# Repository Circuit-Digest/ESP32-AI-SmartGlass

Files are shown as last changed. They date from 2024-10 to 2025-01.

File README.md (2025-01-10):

# [ESP32-AI-SmartGlass](https://circuitdigest.com/videos/esp32-ai-smartglass)
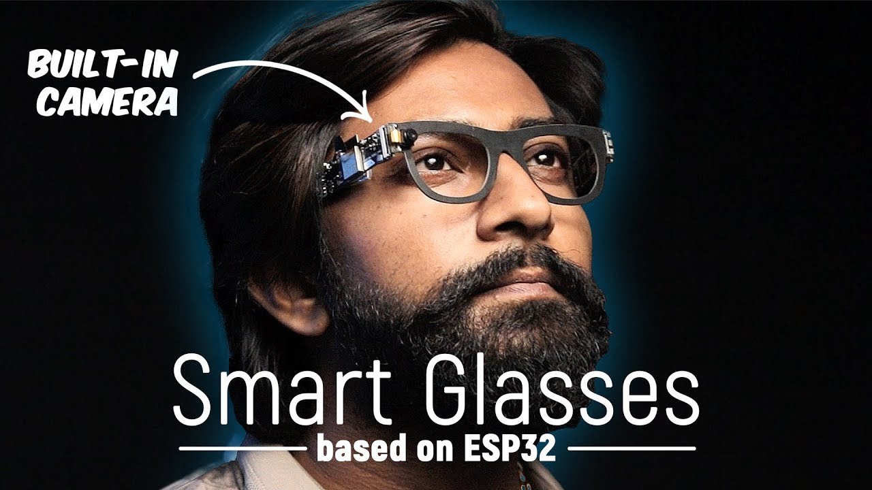
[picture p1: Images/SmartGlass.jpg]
Main Image


<br>
The ESP32 AI Smartglass is an innovative wearable device that blends the power of artificial intelligence with the convenience of home automation. Built around the ESP32-S3 mini microcontroller with 4MB of flash and 2MB of PSRAM, this smartglass is equipped to handle a variety of tasks efficiently. With built-in components like the INMP441 microphone, OV2640 camera, and MAX98357 I2S audio amplifier with a speaker, the smart glass is designed for seamless QR code-based control of household appliances. All the hardware is compactly integrated on a single PCB, which also forms the right leg of the smart glass, providing an elegant and functional solution. One of the standout features of the smart glass is its ease of use and versatility. By utilising the camera to scan QR codes, the user can control devices such as lights or fans connected to the same WiFi network. Once powered on, the RGB LEDs provide visual feedback during WiFi connection attempts, and the smart glass offers a welcome chime when the connection is successful. This smart glass removes the need for complex remote controls or hardwired switches, giving users a hands-free, efficient way to manage home automation with a simple glance at the desired QR code.

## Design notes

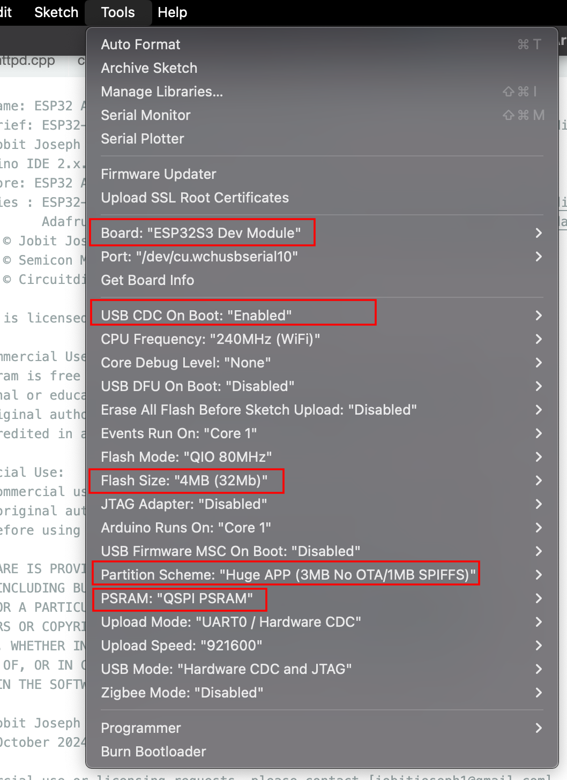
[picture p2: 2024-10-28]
Images/Arduino IDE Board Settings.png

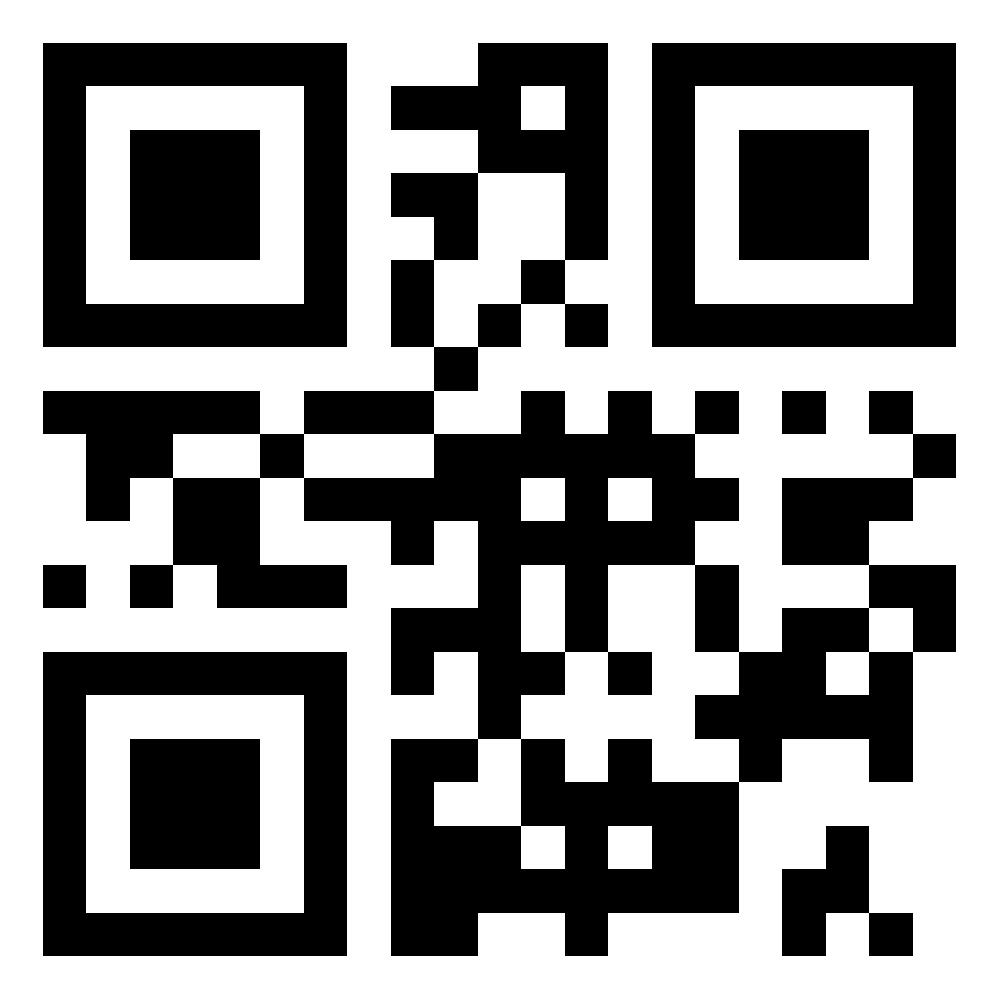
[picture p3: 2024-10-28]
Images/light.png

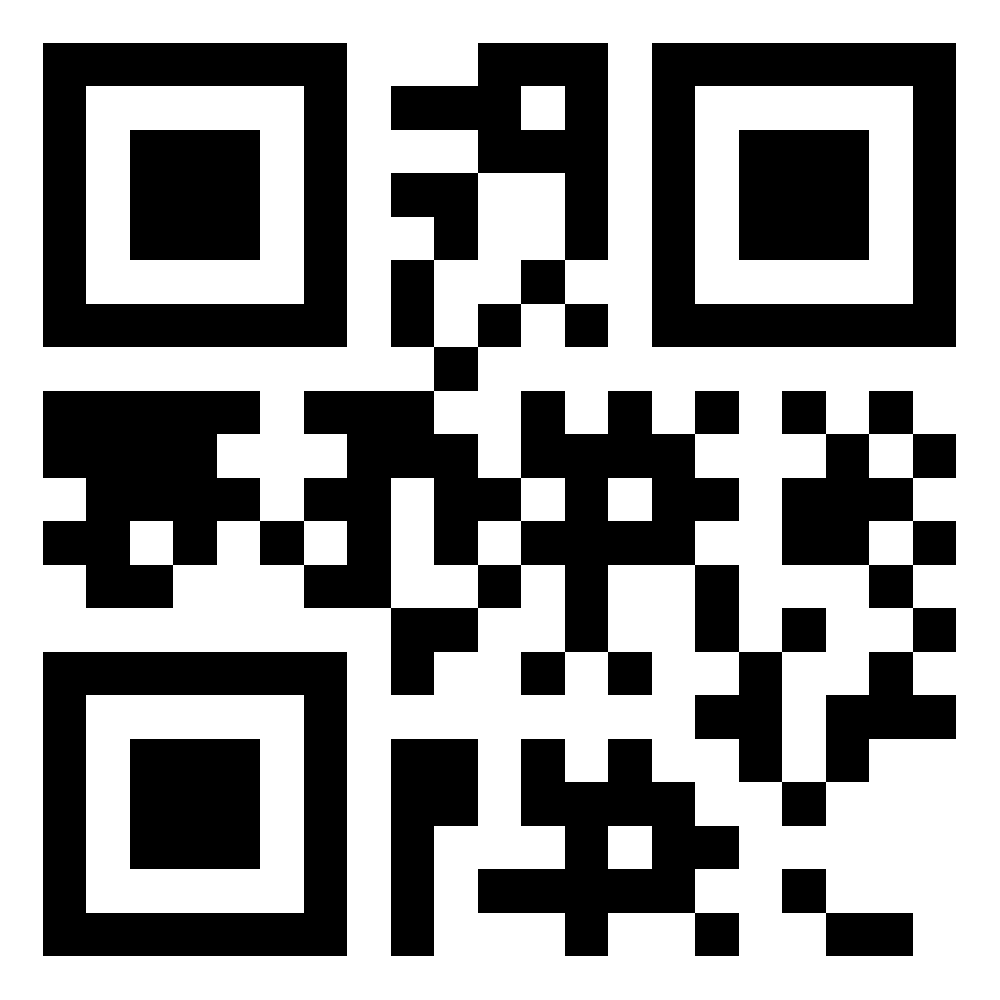
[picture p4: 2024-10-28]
Images/fan.png

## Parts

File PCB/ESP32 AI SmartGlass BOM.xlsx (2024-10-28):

Designator | Value | Footprint | Quantity | Manufacturer | Manufacturer Product Number | DigiKey Part Number | DigiKey Link
C1, C2, C4 | 4.7u | C603 | 3 | Samsung Electro-Mechanics | CL10A475KP8NNNC | 1276-1044-1-ND | https://www.digikey.in/en/products/detail/samsung-electro-mechanics/CL10A475KP8NNNC/3886702
C12 | 2.2uF | C603 | 1 | Samsung Electro-Mechanics | CL10B225KP8NNNC | 1276-1134-1-ND | https://www.digikey.in/en/products/detail/samsung-electro-mechanics/CL10B225KP8NNNC/3886792
C13 | 100nF | C603 | 1 | YAGEO | CC0603KRX7R7BB104 | 311-1088-1-ND | https://www.digikey.in/en/products/detail/yageo/CC0603KRX7R7BB104/302822
C20, C22, C24 | 100nF | C402 | 3 | Murata Electronics | GRM155R71C104KA88J | 490-6328-1-ND | https://www.digikey.in/en/products/detail/murata-electronics/GRM155R71C104KA88J/2610892
C21 | 4.7uF | C402 | 1 | Samsung Electro-Mechanics | CL05A475MP5NRNC | 1276-1482-1-ND | https://www.digikey.in/en/products/detail/samsung-electro-mechanics/CL05A475MP5NRNC/3887140
C23 | 2.2uF | C402 | 1 | Samsung Electro-Mechanics | CL05A225MP5NSNC | 1276-1467-1-ND | https://www.digikey.in/en/products/detail/samsung-electro-mechanics/CL05A225MP5NSNC/3887125
C25, C26, C27, C28 | 1uF | C603 | 4 | YAGEO | CC0603KRX7R7BB105 | 311-1446-1-ND | https://www.digikey.in/en/products/detail/yageo/CC0603KRX7R7BB105/2833611
C3 | 1nF | C603 | 1 | KEMET | C0603C102K5RAC7867 | 399-C0603C102K5RAC7867CT-ND | https://www.digikey.in/en/products/detail/kemet/C0603C102K5RAC7867/411081
D4 | 1N4148WT | D_SOD-523 | 1 | ANBON SEMICONDUCTOR (INT'L) LIMITED | 1N4148WT | 4530-1N4148WTCT-ND | https://www.digikey.in/en/products/detail/anbon-semiconductor-int-l-limited/1N4148WT/17284364
IC1 | LTC4065EDC | SON50P200X200X80-7N-D | 1 | Analog Devices Inc. | LTC4065EDC#TRMPBF | 505-LTC4065EDC#TRMPBFCT-ND | https://www.digikey.in/en/products/detail/analog-devices-inc/LTC4065EDC-TRMPBF/1115982
IC2 | ADM7171ACPZ-3.3-R7 | SON50P300X300X80-9N-D | 1 | Analog Devices Inc. | ADM7171ACPZ-3.3-R7 | 505-ADM7171ACPZ-3.3-R7CT-ND | https://www.digikey.in/en/products/detail/analog-devices-inc/ADM7171ACPZ-3-3-R7/5011539
IC5 | MAX98357AETE+T | QFN50P300X300X80-17N | 1 | Analog Devices Inc./Maxim Integrated | MAX98357AETE+T | MAX98357AETE+TCT-ND | https://www.digikey.in/en/products/detail/analog-devices-inc-maxim-integrated/MAX98357AETE-T/4936122
J2 | 10118194-0001LF | AMPHENOL_10118194-0001LF | 1 | Amphenol ICC (FCI) | 10118194-0001LF | 609-4618-1-ND | https://www.digikey.in/en/products/detail/amphenol-icc-(fci)/10118194-0001LF/2785382?productid=2785382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
J5 | Conn_01x24 | TE_2-1734839-4_1x24-1MP_P0.5mm_Horizontal | 1 | Amphenol ICC (FCI) | F33Z-1A7Q1-E8C24 | 609-F33Z-1A7Q1-E8C24CT-ND | https://www.digikey.in/en/products/detail/amphenol-cs-fci/F33Z-1A7Q1-E8C24/20415093
LED1 | Red | LED603 | 1 | Harvatek Corporation | B1911USD-20D000114U1930 | 3147-B1911USD-20D000114U1930CT-ND | https://www.digikey.in/en/products/detail/harvatek-corporation/B1911USD-20D000114U1930/15519991
R1 | 510R | R603 | 1 | YAGEO | RC0603FR-07510RL | 311-510HRCT-ND | https://www.digikey.in/en/products/detail/yageo/RC0603FR-07510RL/727285
R10, R9 | 10k | R402 | 2 | YAGEO | RC0402JR-0710KL | 311-10KJRCT-ND | https://www.digikey.in/en/products/detail/yageo/RC0402JR-0710KL/726418
R12 | 0R | R603 | 1 | Stackpole Electronics Inc | RMCF0603ZT0R00 | RMCF0603ZT0R00CT-ND | https://www.digikey.in/en/products/detail/stackpole-electronics-inc/RMCF0603ZT0R00/1756908
R2 | 2K | R603 | 1 | Panasonic Electronic Components | ERJ-3EKF2001V | P2.00KHCT-ND | https://www.digikey.in/en/products/detail/panasonic-electronic-components/ERJ-3EKF2001V/196183
R3 | 100K | R603 | 1 | Panasonic Electronic Components | ERJ-3EKF1003V | P100KHCT-ND | https://www.digikey.in/en/products/detail/panasonic-electronic-components/ERJ-3EKF1003V/196075
R4, R5 | 10k | R603 | 2 | Stackpole Electronics Inc | RMCF0603JT10K0 | RMCF0603JT10K0CT-ND | https://www.digikey.in/en/products/detail/stackpole-electronics-inc/RMCF0603JT10K0/1758104
SW1 | CUS-12TB | slide switch spdt | 1 | Nidec Components Corporation | CUS-12TB | 563-1102-1-ND | https://www.digikey.in/en/products/detail/nidec-components-corporation/CUS-12TB/1124222
SW2, SW3 | RST | Tactile 3x4x2mm TS-A010 | 2 | CIT Relay and Switch | CS1213AGF160 | 2449-CS1213AGF160CT-ND | https://www.digikey.in/en/products/detail/cit-relay-and-switch/CS1213AGF160/16607723
U2 | AP2127K-2.8 | SOT-23-5 | 1 | Diodes Incorporated | AP2127K-2.8TRG1 | AP2127K-2.8TRG1DICT-ND | https://www.digikey.in/en/products/detail/diodes-incorporated/AP2127K-2-8TRG1/4570641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
U3 | ESP32-S3-MINI-1U | ESP32-S2-MINI-1U | 1 | Espressif Systems | ESP32-S3-MINI-1-N4R2 | 1965-ESP32-S3-MINI-1-N4R2CT-ND | https://www.digikey.in/en/products/detail/espressif-systems/ESP32-S3-MINI-1-N4R2/22597234
U4 | AP2127K-1.5 | SOT-23-5 | 1 | Diodes Incorporated | AP2127K-1.8TRG1 | AP2127K-1.8TRG1DICT-ND | https://www.digikey.in/en/products/detail/diodes-incorporated/AP2127K-1-5TRG1/4470783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

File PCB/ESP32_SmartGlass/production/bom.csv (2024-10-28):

Designator | Footprint | Quantity | Value | LCSC Part #
BZ2 | JST_PH_B2B-PH-K_1x02_P2.00mm_Vertical | 1 | SMT-0540-S-R
C1, C2, C4 | 0603 | 3 | 4.7u
C12 | 0603 | 1 | 2.2uF
C13 | 0603 | 1 | 100nF
C20, C22 | 0402 | 2 | 100nf
C21 | 0402 | 1 | 4.7uf
C25, C26, C27, C28, C29, C30 | 0603 | 6 | 1u
C3 | 0603 | 1 | 1n
D1, D2 | LED_WS2812B-2020_PLCC4_2.0x2.0mm | 2 | WS2812B-2020
FB1, FB2 | 0805 | 2 | FerriteBead_Small
IC1 | SON50P200X200X80-7N-D | 1 | LTC4065EDC
IC2 | SON50P300X300X80-9N-D | 1 | ADM7171ACPZ-3.3-R7
IC5 | QFN50P300X300X80-17N | 1 | MAX98357AETE+T
J1 | PinHeader_1x02_P2.00mm_Vertical | 1 | Conn_01x02
J2 | AMPHENOL_10118194-0001LF | 1 | 10118194-0001LF
J3 | PinHeader_1x01_P2.54mm_Vertical | 1 | Conn_01x01
J5_2 | PinHeader_1x15_P1.00mm_Vertical | 1 | Conn_01x15
J5 | TE_2-1734839-4_1x24-1MP_P0.5mm_Horizontal | 1 | Conn_01x24
LED1 | 0603 | 1 | Red
MK1 | MIC_INMP441ACEZ-R7 | 1 | INMP441ACEZ-R7
R1 | 0603 | 1 | 510
R10, R9 | 0402 | 2 | 10k
R11, R6 | 0603 | 2 | NC
R12 | 0603 | 1 | 0R
R2 | 0603 | 1 | 2K
R3 | 0603 | 1 | 100K
R4, R5 | 0603 | 2 | 10k
SW1 | slide switch spdt | 1 | K3-1280S-F1
SW2 | Tactile 3x4x2mm TS-A010 | 1 | RST
SW3 | Tactile 3x4x2mm TS-A010 | 1 | BOOT
U2 | SOT-23-5 | 1 | AP2127K-2.8
U3 | ESP32-S2-MINI-1U | 1 | ESP32-S3-MINI-1U
U4 | SOT-23-5 | 1 | AP2127K-1.8

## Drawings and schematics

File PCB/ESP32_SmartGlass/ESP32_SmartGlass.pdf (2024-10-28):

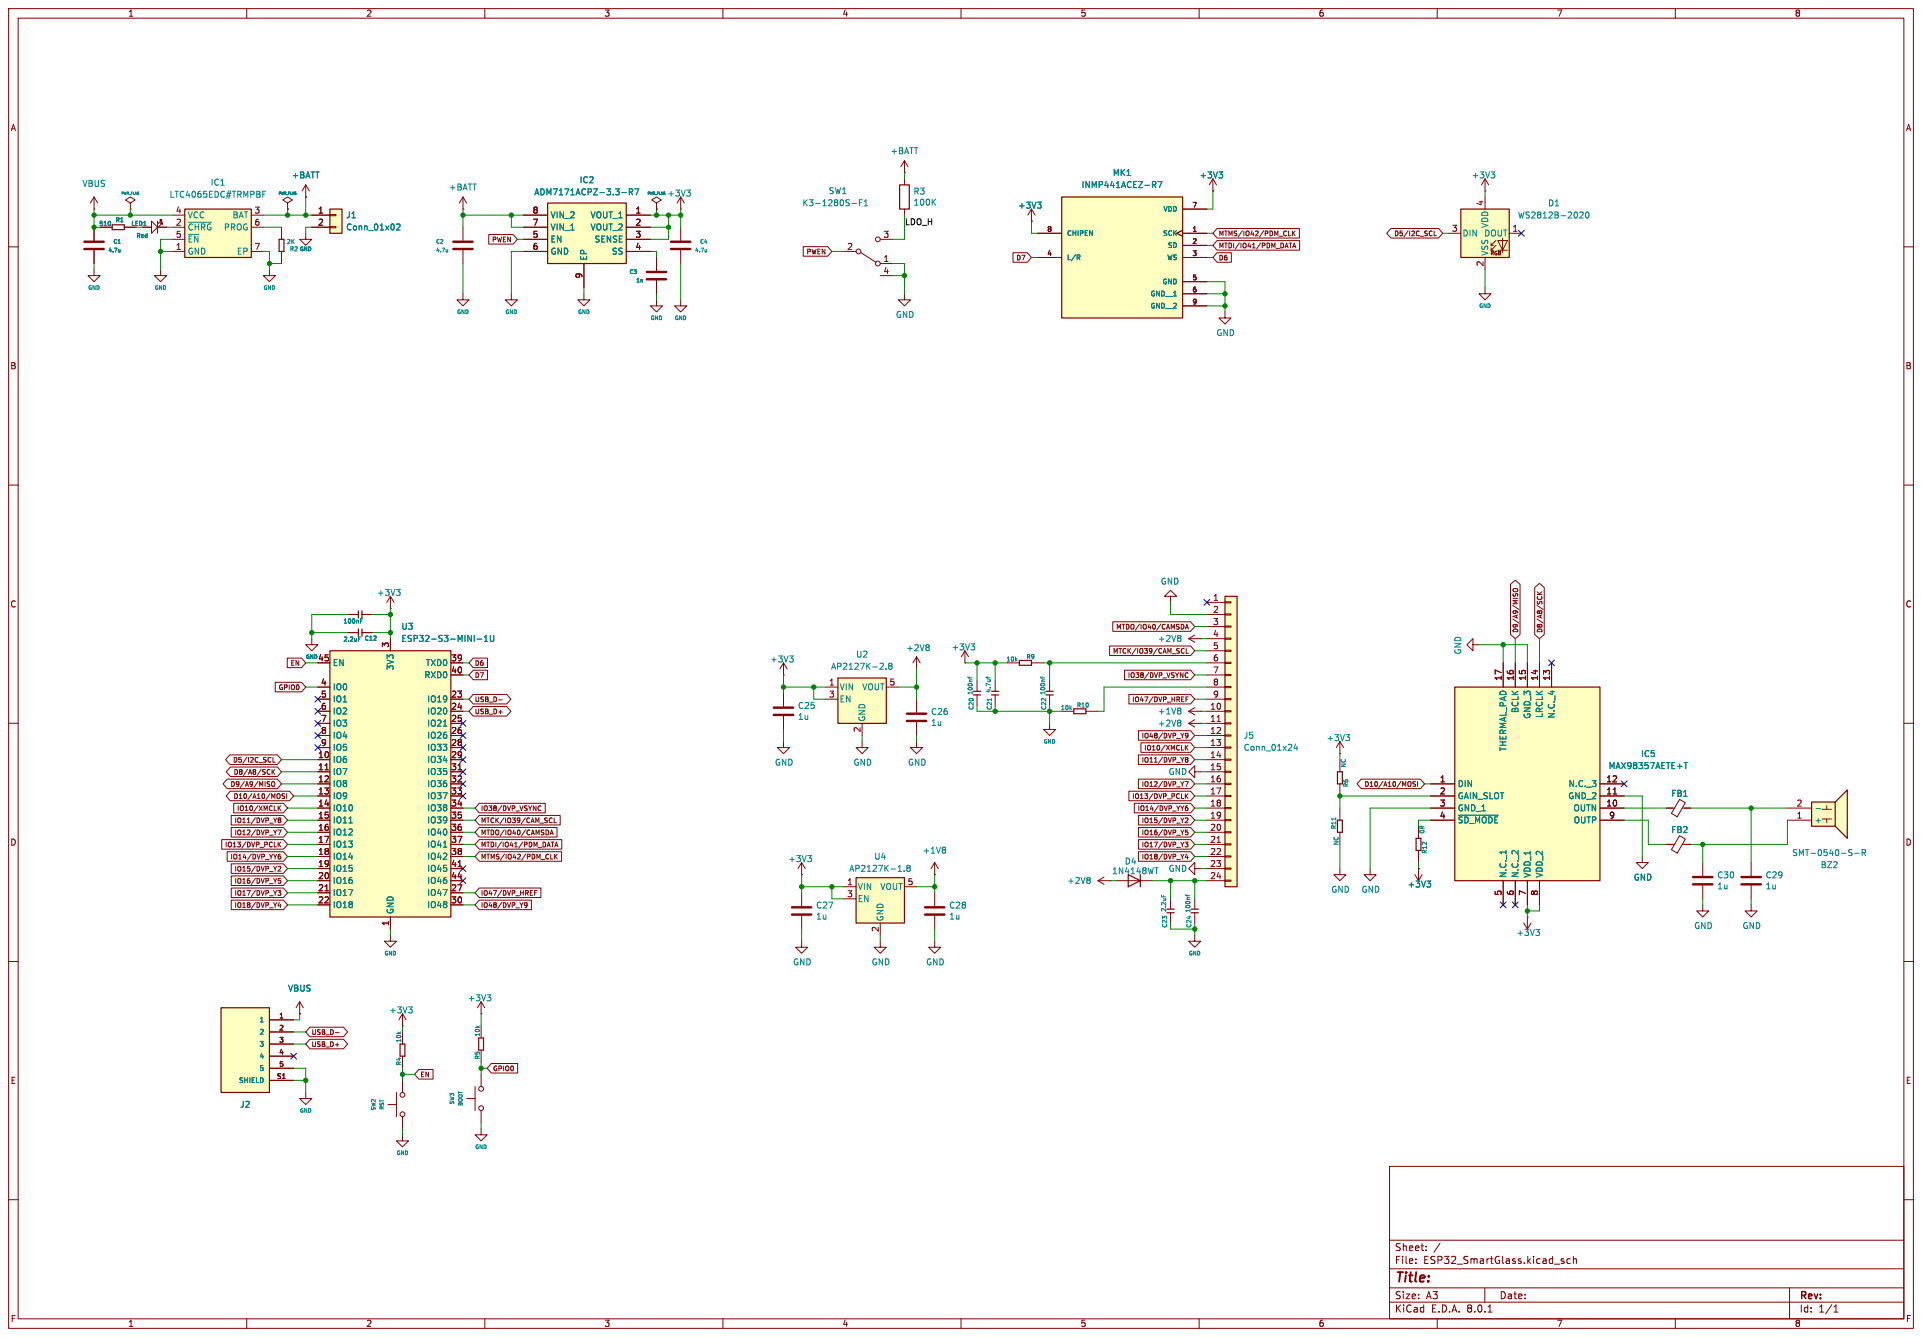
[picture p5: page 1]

D10/A10/MOSI MTCK/IO39/CAM_SCL MTDO/IO40/CAMSDA

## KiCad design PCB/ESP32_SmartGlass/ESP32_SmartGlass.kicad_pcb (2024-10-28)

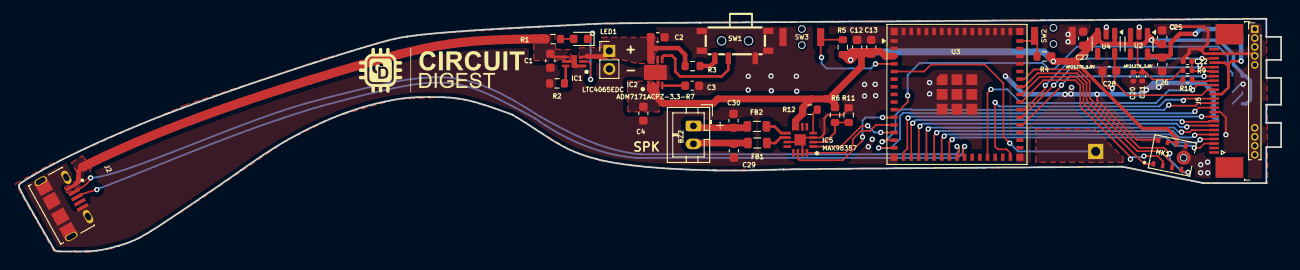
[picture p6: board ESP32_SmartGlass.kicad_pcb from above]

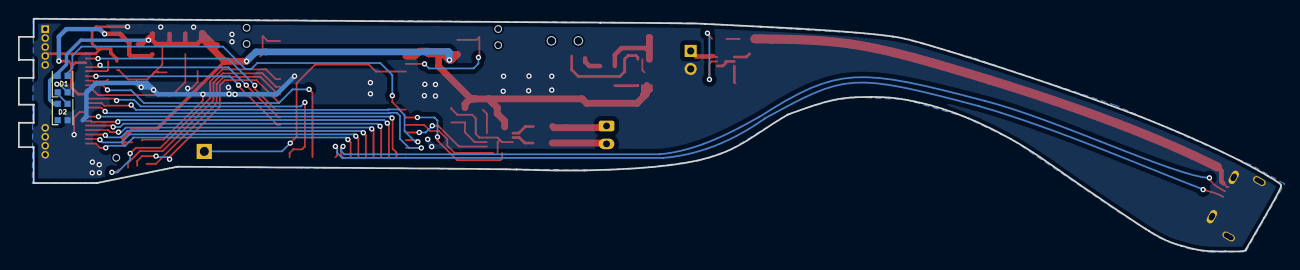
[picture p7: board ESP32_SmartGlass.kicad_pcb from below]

Board: 2 copper layers, 140.6 x 25.9 mm, 46 parts (2 on the bottom side), 48 nets.

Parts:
BZ2: SMT-0540-S-R; JST_PH_B2B-PH-K_1x02_P2.00mm_Vertical
C1, C2, C4: 4.7u; C_0603_1608Metric
C3: 1n; C_0603_1608Metric
C12: 2.2uF; C_0603_1608Metric
C13: 100nF; C_0603_1608Metric
C20, C22: 100nf; C_0402_1005Metric
C21: 4.7uf; C_0402_1005Metric
C25, C26, C27, C28, C29, C30: 1u; C_0603_1608Metric
D1, D2: WS2812B-2020; LED_WS2812B-2020_PLCC4_2.0x2.0mm
FB1, FB2: FerriteBead_Small; L_0805_2012Metric
IC1: LTC4065EDC; SON50P200X200X80-7N-D
IC2: ADM7171ACPZ-3.3-R7; SON50P300X300X80-9N-D
IC5: MAX98357AETE+T; QFN50P300X300X80-17N
J1: Conn_01x02; PinHeader_1x02_P2.00mm_Vertical
J2: 10118194-0001LF; AMPHENOL_10118194-0001LF
J3: Conn_01x01; PinHeader_1x01_P2.54mm_Vertical
J5: Conn_01x15; PinHeader_1x15_P1.00mm_Vertical
J5#2: Conn_01x24; TE_2-1734839-4_1x24-1MP_P0.5mm_Horizontal
LED1: Red; LED_0603_1608Metric
MK1: INMP441ACEZ-R7; MIC_INMP441ACEZ-R7
R1: 510; R_0603_1608Metric
R2: 2K; R_0603_1608Metric
R3: 100K; R_0603_1608Metric
R4, R5: 10k; R_0603_1608Metric
R6, R11: NC; R_0603_1608Metric
R9, R10: 10k; R_0402_1005Metric
R12: 0R; R_0603_1608Metric
SW1: K3-1280S-F1; slide switch spdt
SW2: RST; Tactile 3x4x2mm TS-A010
SW3: BOOT; Tactile 3x4x2mm TS-A010
U2: AP2127K-2.8; SOT-23-5
U3: ESP32-S3-MINI-1U; ESP32-S2-MINI-1U
U4: AP2127K-1.8; SOT-23-5

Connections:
+1V8: C28.1, J5#2.10, U4.5 (VOUT)
+2V8: C26.1, J5#2.4, J5#2.11, U2.5 (VOUT)
+3V3: C4.1, C12.2, C13.2, C20.1, C21.1, C25.1, C27.1, D1.4 (VDD), D2.4 (VDD), IC2.1 (VOUT_1), IC2.2 (VOUT_2), IC2.3 (SENSE), IC5.7 (VDD_1), IC5.8 (VDD_2), MK1.7 (VDD), MK1.8 (CHIPEN), R4.1, R5.1, R6.1, R9.1, R12.2, U2.1 (VIN), U2.3 (EN), U3.3 (3V3), U4.1 (VIN), U4.3 (EN)
+BATT: C2.1, IC1.3 (BAT), IC2.7 (VIN_1), IC2.8 (VIN_2), J1.1, R3.1
/LDO_H: R3.2, SW1.3 (C)
D5/I2C_SCL: D1.3 (DIN), U3.10 (IO6)
D6: MK1.3 (WS), U3.39 (TXD0)
D7: MK1.4 (L/R), U3.40 (RXD0)
D8/A8/SCK: IC5.14 (LRCLK), U3.11 (IO7)
D9/A9/MISO: IC5.16 (BCLK), U3.12 (IO8)
D10/A10/MOSI: IC5.1 (DIN), U3.13 (IO9)
EN: R4.2, SW2.2, U3.45 (EN)
GND: C1.2, C2.2, C3.2, C4.2, C12.1, C13.1, C20.2, C21.2, C22.2, C25.2, C26.2, C27.2, C28.2, C29.2, C30.2, D1.2 (VSS), D2.2 (VSS), IC1.1 (GND), IC1.5 (~EN), IC1.7 (EP), IC2.6 (GND), IC2.9 (EP), IC5.3 (GND_1), IC5.11 (GND_2), IC5.15 (GND_3), IC5.17 (THERMAL_PAD), J1.2, J2.5, J2.S1 (SHIELD), J2.S2 (SHIELD__1), J5.1, J5.2, J5.3, J5.4, J5.5, J5.12, J5.13, J5.14, J5.15, J5#2.2, J5#2.15, MK1.5 (GND), MK1.6 (GND__1), MK1.9 (GND__2), R2.2, R10.1, R11.1, SW1.1 (A), SW1.4, SW2.1, SW3.1, U2.2 (GND), U3.1 (GND), U3.2 (GND), U3.42 (GND), U3.43 (GND), U3.46 (GND), U3.47 (GND), U3.48 (GND), U3.49 (GND), U3.50 (GND), U3.51 (GND), U3.52 (GND), U3.53 (GND), U3.54 (GND), U3.55 (GND), U3.56 (GND), U3.57 (GND), U3.58 (GND), U3.59 (GND), U3.60 (GND), U3.61 (GND), U3.62 (GND), U3.63 (GND), U3.64 (GND), U3.65 (GND), U4.2 (GND)
GPIO0: R5.2, SW3.2, U3.4 (IO0)
IO10/XMCLK: J5#2.13, U3.14 (IO10)
IO11/DVP_Y8: J5#2.14, U3.15 (IO11)
IO12/DVP_Y7: J5#2.16, U3.16 (IO12)
IO13/DVP_PCLK: J5#2.17, U3.17 (IO13)
IO14/DVP_YY6: J5#2.18, U3.18 (IO14)
IO15/DVP_Y2: J5#2.19, U3.19 (IO15)
IO16/DVP_Y5: J5#2.20, U3.20 (IO16)
IO17/DVP_Y3: J5#2.21, U3.21 (IO17)
IO18/DVP_Y4: J5#2.22, U3.22 (IO18)
IO38/DVP_VSYNC: J5#2.7, U3.34 (IO38)
IO47/DVP_HREF: J5#2.9, U3.27 (IO47)
IO48/DVP_Y9: J5#2.12, U3.30 (IO48)
MTCK/IO39/CAM_SCL: J5#2.5, U3.35 (IO39)
MTDI/IO41/PDM_DATA: MK1.2 (SD), U3.37 (IO41)
MTDO/IO40/CAMSDA: J5#2.3, U3.36 (IO40)
MTMS/IO42/PDM_CLK: MK1.1 (SCK), U3.38 (IO42)
unnamed: BZ2.1 (+), C30.1, FB2.2
unnamed: BZ2.2 (-), C29.1, FB1.2
unnamed: D1.1 (DOUT), D2.3 (DIN)
unnamed: IC1.6 (PROG), R2.1
unnamed: IC1.2 (~CHRG), LED1.1 (K)
unnamed: C3.1, IC2.4 (SS)
unnamed: IC5.2 (GAIN_SLOT), R6.2, R11.2
unnamed: FB1.1, IC5.10 (OUTN)
unnamed: FB2.1, IC5.9 (OUTP)
unnamed: IC5.4 (~SD_MODE), R12.1
unnamed: J3.1, U3.5 (IO1)
unnamed: C22.1, J5#2.6, R9.2
unnamed: J5#2.8, R10.2
unnamed: LED1.2 (A), R1.2
PWEN: IC2.5 (EN), SW1.2 (B)
USB_D+: J2.3, U3.24 (IO20)
USB_D-: J2.2, U3.23 (IO19)
VBUS: C1.1, IC1.4 (VCC), J2.1, R1.1

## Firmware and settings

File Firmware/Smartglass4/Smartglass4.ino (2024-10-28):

/*
 * Project Name: ESP32 AI Smart Glass
 * Project Brief: ESP32-S3 based smart glass equiped with camera, I2S amp and Memes Microphone. Capable of home automation with QRCode.
 * Author: Jobit Joseph @ https://github.com/jobitjoseph
 * IDE: Arduino IDE 2.x.x
 * Arduino Core: ESP32 Arduino Core V 3.0.5
 * Dependencies : ESP32-audioI2S Library V 3.0.12 @ https://github.com/schreibfaul1/ESP32-audioI2S
 *                Adafruit Neopixel Library V 1.12.3 @ https://github.com/adafruit/Adafruit_NeoPixel
 * Copyright © Jobit Joseph
 * Copyright © Semicon Media Pvt Ltd
 * Copyright © Circuitdigest.com
 * 
 * This code is licensed under the following conditions:
 *
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
 * 2. Commercial Use:
 * For any commercial use of this software, you must obtain a separate license
 * from the original author. Contact the author for permissions or licensing
 * options before using this software for commercial purposes.
 *
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
 * Author: Jobit Joseph
 * Date: 18 October 2024
 *
 * For commercial use or licensing requests, please contact [jobitjoseph1@gmail.com].
 */

#include "esp_camera.h"
#include <WiFi.h>
#include <Adafruit_NeoPixel.h>
#include "Audio.h"
#include "FS.h"
#include <LittleFS.h>
#include <HTTPClient.h>
#define I2S_DOUT 9
#define I2S_BCLK 8
#define I2S_LRC 7
#define RGBPIN 6
#define NUMPIXELS 2
#define FORMAT_LITTLEFS_IF_FAILED true
Adafruit_NeoPixel pixels(NUMPIXELS, RGBPIN, NEO_GRB + NEO_KHZ800);
Audio audio;
WiFiClientSecure client;           // Secure client for HTTPS communication
String receivedText = "";          // Buffer to hold the received serial text
#define CAMERA_MODEL_XIAO_ESP32S3  // Has PSRAM
#include "camera_pins.h"

// ===========================
// Enter your WiFi credentials
// ===========================

const char* ssid = "circuitdigest";
const char* password = "circuitdigest123";

String serverName = "www.circuitdigest.cloud";  // Server domain
String serverPath = "/readqrcode";              // API endpoint path
const int serverPort = 443;                     // HTTPS port
String apiKey = "0Sv8M7UgxMtB";                 // Replace "xxx" with your API key

bool shouldReconnect = false;  // Flag to indicate Wi-Fi disconnection
unsigned long LastConFailedTime = 0;
int threshold = 1000;
bool touchdetected = false;
bool touchreleased = false;
bool EQ1 = false;
bool EQ2 = false;
void startCameraServer();
void setupLedFlash(int pin);
void TouchITR() {
  touchdetected = (touchdetected == false) ? true : false;
  touchreleased = (touchdetected == true) ? touchreleased : true;
}
void initWiFi() {
  Serial.print("Connecting to ");
  Serial.println(ssid);
  //audio.connecttoFS(LittleFS, "/Connecting.mp3");
  WiFi.disconnect();
  WiFi.mode(WIFI_STA);
  WiFi.begin(ssid, password);
  WiFi.setSleep(false);
  unsigned long startAttemptTime = millis();
  while (WiFi.status() != WL_CONNECTED) {
    if (millis() - startAttemptTime > 15000) {  // Timeout after 10 seconds
      Serial.println("Failed to connect to WiFi");
      //audio.connecttoFS(LittleFS, "/ConnectionFailed.mp3");
      LastConFailedTime = millis();
      return;  // Exit if unable to connect
    }
    delay(250);
    Serial.print(".");
    pixels.setPixelColor(0, pixels.Color(0, 0, 255));
    pixels.show();
    delay(250);
    pixels.clear();
    pixels.show();
    touchreleased = false;
  }
}
void onWifiEvent(WiFiEvent_t event) {
  switch (event) {
    case ARDUINO_EVENT_WIFI_STA_GOT_IP:
      Serial.println("");
      Serial.println("Connected to Wi-Fi successfully.");
      Serial.print("IP address: ");
      Serial.println(WiFi.localIP());
      //audio.connecttoFS(LittleFS, "/WiFiActive.mp3");
      shouldReconnect = false;  // Reset flag on successful connection
      break;

    case WIFI_EVENT_STA_DISCONNECTED:
      Serial.println("Disconnected from Wi-Fi, will try to reconnect...");
      shouldReconnect = true;  // Set flag to reconnect in the loop
      break;

    default:
      break;
  }
}
void initFS() {
  if (!LittleFS.begin(FORMAT_LITTLEFS_IF_FAILED)) {
    Serial.println("LittleFS Mount Failed");
    return;
  }
}

void togglePinOnESP8266(const char* esp8266_hostname) {
  if (WiFi.status() == WL_CONNECTED) {
    HTTPClient http;
    String url = String("http://") + esp8266_hostname + ".local/toggle";
    http.begin(url);
    int httpCode = http.GET();
    http.end();
  }
}

int getPinStateFromESP8266(const char* esp8266_hostname) {
  if (WiFi.status() == WL_CONNECTED) {
    HTTPClient http;
    String url = String("http://") + esp8266_hostname + ".local/state";
    http.begin(url);
    int httpCode = http.GET();
    String payload = http.getString();  // Get the response

    http.end();

    // Convert response to 0 or 1 based on the state
    if (payload == "HIGH") {
      return 1;
    } else if (payload == "LOW") {
      return 0;
    }
  }
  return -1;  // Return -1 if there is an error
}
/*
// Function to extract a JSON array value by key
String extractJsonArrayValue(const String& jsonString, const String& key) {
  int keyIndex = jsonString.indexOf(key);
  if (keyIndex == -1) {
    return "";
  }

  int startIndex = jsonString.indexOf('[', keyIndex);
  int endIndex = jsonString.indexOf(']', startIndex);

  if (startIndex == -1 || endIndex == -1) {
    return "";
  }

  return jsonString.substring(startIndex, endIndex + 1);
}


// Function to extract a JSON array value by key
String extractJsonArrayValue(const String& jsonString, const String& key) {
  int keyIndex = jsonString.indexOf(key);
  if (keyIndex == -1) {
    return "";
  }

  int startIndex = jsonString.indexOf('[', keyIndex);
  int endIndex = jsonString.indexOf(']', startIndex);

  if (startIndex == -1 || endIndex == -1) {
    return "";
  }

  // Extract the string inside the array, remove the square brackets and quotes
  String extractedArray = jsonString.substring(startIndex + 1, endIndex);
  extractedArray.replace("\"", ""); // Remove the double quotes

  return extractedArray;
}
*/
String extractJsonArrayValue(const String& jsonString, const String& key) {
    int keyIndex = jsonString.indexOf(key);
    if (keyIndex == -1) {
        return "";
    }

    int startIndex = jsonString.indexOf('[', keyIndex);
    int endIndex = jsonString.indexOf(']', startIndex);

    if (startIndex == -1 || endIndex == -1) {
        return "";
    }

    // Extract the string inside the array, remove the square brackets and quotes
    String extractedArray = jsonString.substring(startIndex + 1, endIndex);
    extractedArray.replace("\"", ""); // Remove the double quotes

    // Split the extractedArray by commas and return the first element
    int commaIndex = extractedArray.indexOf(',');
    if (commaIndex != -1) {
        return extractedArray.substring(0, commaIndex); // Return the first value before the comma
    }

    // If there is no comma, return the extractedArray (it contains only one element)
    return extractedArray;
}

// Function to extract a JSON string value by key
String extractJsonStringValue(const String& jsonString, const String& key) {
  int keyIndex = jsonString.indexOf(key);
  if (keyIndex == -1) {
    return "";
  }

  int startIndex = jsonString.indexOf(':', keyIndex) + 2;
  int endIndex = jsonString.indexOf('"', startIndex);

  if (startIndex == -1 || endIndex == -1) {
    return "";
  }

  return jsonString.substring(startIndex, endIndex);
}

// Function to capture and send photo to the server
int sendPhoto() {
  camera_fb_t* fb = NULL;
  fb = esp_camera_fb_get();
  if (!fb) {
    Serial.println("Camera capture failed");
    touchreleased = false;
    pixels.setPixelColor(0, pixels.Color(255, 0, 0));
    pixels.show();
    delay(250);
    pixels.clear();
    pixels.show();
    return -1;
  }

  // Display success message
  Serial.println("Image Capture Success");
  // Connect to server
  Serial.println("Connecting to server:" + serverName);
  client.setInsecure();  // Skip certificate validation for simplicity

  pixels.setPixelColor(0, pixels.Color(0, 255, 0));
  pixels.show();

  if (client.connect(serverName.c_str(), serverPort)) {
    Serial.println("Connection successful!");
    String filename = apiKey + ".jpeg";

    // Prepare HTTP POST request
    String head = "--CircuitDigest\r\nContent-Disposition: form-data; name=\"imageFile\"; filename=\"" + filename + "\"\r\nContent-Type: image/jpeg\r\n\r\n";
    String tail = "\r\n--CircuitDigest--\r\n";
    uint32_t imageLen = fb->len;
    uint32_t extraLen = head.length() + tail.length();
    uint32_t totalLen = imageLen + extraLen;

    client.println("POST " + serverPath + " HTTP/1.1");
    client.println("Host: " + serverName);
    client.println("Content-Length: " + String(totalLen));
    client.println("Content-Type: multipart/form-data; boundary=CircuitDigest");
    client.println("Authorization:" + apiKey);
    client.println();
    client.print(head);

    // Send image data in chunks
    uint8_t* fbBuf = fb->buf;
    size_t fbLen = fb->len;
    for (size_t n = 0; n < fbLen; n += 1024) {
      if (n + 1024 < fbLen) {
        client.write(fbBuf, 1024);
        fbBuf += 1024;
      } else {
        size_t remainder = fbLen % 1024;
        client.write(fbBuf, remainder);
      }
    }

    client.print(tail);

    // Clean up
    esp_camera_fb_return(fb);

    // Wait for server response
    String response;
    long startTime = millis();
    while (client.connected() && millis() - startTime < 10000) {
      if (client.available()) {
        char c = client.read();
        response += c;
      }
    }
    Serial.println("Raw JSON Data: " + response);
    // Extract and display QR code data from response
    String qrCodeData = extractJsonArrayValue(response, "\"QR_code\"");
    String imageLink = extractJsonStringValue(response, "\"view_image\"");

    Serial.print("QR Data: ");
    Serial.println(qrCodeData);
    if (qrCodeData == "light") {
      EQ1 = true;
    } else if (qrCodeData == "fan") {
      EQ2 = true;
    } else {
      audio.connecttoFS(LittleFS, "/InvalidQR.mp3");
    }

    Serial.print("ImageLink: ");
    Serial.println(imageLink);

    // Serial.print("Response Json String: ");
    // Serial.println(response);


    //displayText("QR Code Data:\n\n" + qrCodeData);

    client.stop();
    touchreleased = false;
    pixels.clear();
    pixels.show();
    return 0;
  } else {
    Serial.println("Connection to server failed");
    touchreleased = false;
    pixels.setPixelColor(0, pixels.Color(255, 0, 0));
    pixels.show();
    delay(200);
    pixels.clear();
    pixels.show();
    pixels.setPixelColor(0, pixels.Color(255, 0, 0));
    pixels.show();
    delay(200);
    pixels.clear();
    pixels.show();
    return -2;
  }
}
void EQControl() {
  int pinstate;
  if (EQ1) {
    EQ1 = false;
    togglePinOnESP8266("esp8266-1");
    pinstate = getPinStateFromESP8266("esp8266-1");
    if (pinstate == 0) {
      audio.connecttoFS(LittleFS, "/LightOff.mp3");
    } else if (pinstate == 1) {
      audio.connecttoFS(LittleFS, "/LightOn.mp3");
    }
  } else if (EQ2) {
    EQ2 = false;
    togglePinOnESP8266("esp8266-2");
    pinstate = getPinStateFromESP8266("esp8266-2");
    if (pinstate == 0) {
      audio.connecttoFS(LittleFS, "/FanOff.mp3");
    } else if (pinstate == 1) {
      audio.connecttoFS(LittleFS, "/FanOn.mp3");
    }
  }
  touchreleased = false;
}

void setup() {
  Serial.begin(115200);
  Serial.setDebugOutput(true);
  Serial.println();

  camera_config_t config;
  config.ledc_channel = LEDC_CHANNEL_0;
  config.ledc_timer = LEDC_TIMER_0;
  config.pin_d0 = Y2_GPIO_NUM;
  config.pin_d1 = Y3_GPIO_NUM;
  config.pin_d2 = Y4_GPIO_NUM;
  config.pin_d3 = Y5_GPIO_NUM;
  config.pin_d4 = Y6_GPIO_NUM;
  config.pin_d5 = Y7_GPIO_NUM;
  config.pin_d6 = Y8_GPIO_NUM;
  config.pin_d7 = Y9_GPIO_NUM;
  config.pin_xclk = XCLK_GPIO_NUM;
  config.pin_pclk = PCLK_GPIO_NUM;
  config.pin_vsync = VSYNC_GPIO_NUM;
  config.pin_href = HREF_GPIO_NUM;
  config.pin_sccb_sda = SIOD_GPIO_NUM;
  config.pin_sccb_scl = SIOC_GPIO_NUM;
  config.pin_pwdn = PWDN_GPIO_NUM;
  config.pin_reset = RESET_GPIO_NUM;
  config.xclk_freq_hz = 20000000;
  config.frame_size = FRAMESIZE_UXGA;
  config.pixel_format = PIXFORMAT_JPEG;  // for streaming
  //config.pixel_format = PIXFORMAT_RGB565; // for face detection/recognition
  config.grab_mode = CAMERA_GRAB_WHEN_EMPTY;
  config.fb_location = CAMERA_FB_IN_PSRAM;
  //config.fb_location = CAMERA_FB_IN_DRAM;
  config.jpeg_quality = 12;
  config.fb_count = 1;

  // if PSRAM IC present, init with UXGA resolution and higher JPEG quality
  //                      for larger pre-allocated frame buffer.
  if (config.pixel_format == PIXFORMAT_JPEG) {
    if (psramFound()) {
      config.jpeg_quality = 10;
      config.fb_count = 2;
      config.grab_mode = CAMERA_GRAB_LATEST;
    } else {
      // Limit the frame size when PSRAM is not available
      config.frame_size = FRAMESIZE_SVGA;
      config.fb_location = CAMERA_FB_IN_DRAM;
    }
  } else {
    // Best option for face detection/recognition
    config.frame_size = FRAMESIZE_240X240;
#if CONFIG_IDF_TARGET_ESP32S3
    config.fb_count = 1;
#endif
  }



  // camera init
  esp_err_t err = esp_camera_init(&config);
  if (err != ESP_OK) {
    Serial.printf("Camera init failed with error 0x%x", err);
    return;
  }

  sensor_t* s = esp_camera_sensor_get();
  // initial sensors are flipped vertically and colors are a bit saturated
  if (s->id.PID == OV3660_PID) {
    s->set_vflip(s, 1);        // flip it back
    s->set_brightness(s, 1);   // up the brightness just a bit
    s->set_saturation(s, -2);  // lower the saturation
  }
  // drop down frame size for higher initial frame rate
  if (config.pixel_format == PIXFORMAT_JPEG) {
    s->set_framesize(s, FRAMESIZE_QVGA);
  }
/*
#if defined(CAMERA_MODEL_M5STACK_WIDE) || defined(CAMERA_MODEL_M5STACK_ESP32CAM)
  s->set_vflip(s, 1);
  s->set_hmirror(s, 1);
#endif
*/

// Setup LED FLash if LED pin is defined in camera_pins.h
#if defined(LED_GPIO_NUM)
  setupLedFlash(LED_GPIO_NUM);
#endif

  initFS();
  pixels.begin();
  pixels.show();
  pixels.setBrightness(64);
  audio.setPinout(I2S_BCLK, I2S_LRC, I2S_DOUT);
  audio.setVolume(21);
  audio.connecttoFS(LittleFS, "/WelcomeTone.mp3");
  // Register Wi-Fi event handler
  WiFi.onEvent(onWifiEvent);
  //audio.connecttoFS(LittleFS, "/Connecting.mp3");
  initWiFi();
  startCameraServer();

  Serial.print("Camera Ready! Use 'http://");
  Serial.print(WiFi.localIP());
  Serial.println("' to connect");

  touchAttachInterrupt(T1, TouchITR, threshold);
}

void loop() {
  audio.loop();  // Required to keep audio running
  if (WiFi.status() != WL_CONNECTED) {
    if (shouldReconnect || (millis() - LastConFailedTime > 10000)) {
      Serial.println("Reconnecting to Wi-Fi...");
      //audio.connecttoFS(LittleFS, "/Reconnecting.mp3");
      initWiFi();  // Reattempt connection
    }
    if (touchreleased) {
      touchreleased = false;
      audio.connecttoFS(LittleFS, "/NotAvailable.mp3");
    }
  } else {
    SerialControl();
    if (touchreleased) {
      touchreleased = false;
      //audio.connecttospeech("Touch detected", "en");
      int status = sendPhoto();
      EQControl();
      if (status == -1) {
        audio.connecttoFS(LittleFS, "/ICFailed.mp3");
      } else if (status == -2) {
        audio.connecttoFS(LittleFS, "/SeverFailed.mp3");
      }
    }
  }
}

void SerialControl() {
  int pinstate;
  if (Serial.available()) {
    String command = Serial.readStringUntil('\n');  // Read serial input until newline character
    command.trim();                                 // Remove any leading/trailing whitespace

    if (isValidCommand(command)) {
      if (command == "esp8266-1") {
        togglePinOnESP8266("esp8266-1");
        pinstate = getPinStateFromESP8266("esp8266-1");
        if (pinstate == 0) {
          audio.connecttoFS(LittleFS, "/LightOff.mp3");
        } else if (pinstate == 1) {
          audio.connecttoFS(LittleFS, "/LightOn.mp3");
        }
      } else {
        togglePinOnESP8266("esp8266-2");
        pinstate = getPinStateFromESP8266("esp8266-2");
        if (pinstate == 0) {
          audio.connecttoFS(LittleFS, "/FanOff.mp3");
        } else if (pinstate == 1) {
          audio.connecttoFS(LittleFS, "/FanOn.mp3");
        }
      }
    } else {
      Serial.println("Invalid command.");
    }
  }
}
// Function to validate if the command is a valid or not
bool isValidCommand(String cmd) {
  return cmd == "esp8266-1" || cmd == "esp8266-2";
}
/*
void SerialPlay() {
  // Check if there's data available on the serial port
  while (Serial.available() > 0) {
    char receivedChar = Serial.read();
    // Append each character to the receivedText string
    if (receivedChar == '\n') {
      // When a new line is detected, play the received text
      receivedText.trim();  // Remove any leading/trailing whitespace
      if (receivedText.length() > 0) {
        Serial.print("Playing: ");
        Serial.println(receivedText);
        audio.connecttospeech(receivedText.c_str(), "en");  // Play received text
      }
      receivedText = "";  // Clear the buffer for the next input
    } else {
      receivedText += receivedChar;  // Add character to the buffer
    }
  }
}

void audio_info(const char* info) {
  Serial.print("audio_info: ");
  Serial.println(info);
}
*/

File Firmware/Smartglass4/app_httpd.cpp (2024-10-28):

// Copyright 2015-2016 Espressif Systems (Shanghai) PTE LTD
//
// Licensed under the Apache License, Version 2.0 (the "License");
// you may not use this file except in compliance with the License.
// You may obtain a copy of the License at
//
//     http://www.apache.org/licenses/LICENSE-2.0
//
// Unless required by applicable law or agreed to in writing, software
// distributed under the License is distributed on an "AS IS" BASIS,
// WITHOUT WARRANTIES OR CONDITIONS OF ANY KIND, either express or implied.
// See the License for the specific language governing permissions and
// limitations under the License.
#include "esp_http_server.h"
#include "esp_timer.h"
#include "esp_camera.h"
#include "img_converters.h"
#include "fb_gfx.h"
#include "esp32-hal-ledc.h"
#include "sdkconfig.h"
#include "camera_index.h"

#if defined(ARDUINO_ARCH_ESP32) && defined(CONFIG_ARDUHAL_ESP_LOG)
#include "esp32-hal-log.h"
#endif

// Face Detection will not work on boards without (or with disabled) PSRAM
#ifdef BOARD_HAS_PSRAM
// Face Recognition takes upward from 15 seconds per frame on chips other than ESP32S3
// Makes no sense to have it enabled for them
#if CONFIG_IDF_TARGET_ESP32S3
#define CONFIG_ESP_FACE_RECOGNITION_ENABLED 0
#define CONFIG_ESP_FACE_DETECT_ENABLED      0
#else
#define CONFIG_ESP_FACE_RECOGNITION_ENABLED 0
#define CONFIG_ESP_FACE_DETECT_ENABLED      0
#endif
#else
#define CONFIG_ESP_FACE_DETECT_ENABLED      0
#define CONFIG_ESP_FACE_RECOGNITION_ENABLED 0
#endif

#if CONFIG_ESP_FACE_DETECT_ENABLED

#include <vector>
#include "human_face_detect_msr01.hpp"
#include "human_face_detect_mnp01.hpp"

#define TWO_STAGE 1 /*<! 1: detect by two-stage which is more accurate but slower(with keypoints). */
                    /*<! 0: detect by one-stage which is less accurate but faster(without keypoints). */

#if CONFIG_ESP_FACE_RECOGNITION_ENABLED
#pragma GCC diagnostic ignored "-Wformat"
#pragma GCC diagnostic ignored "-Wstrict-aliasing"
#include "face_recognition_tool.hpp"
#include "face_recognition_112_v1_s16.hpp"
#include "face_recognition_112_v1_s8.hpp"
#pragma GCC diagnostic error "-Wformat"
#pragma GCC diagnostic warning "-Wstrict-aliasing"

#define QUANT_TYPE 0  //if set to 1 => very large firmware, very slow, reboots when streaming...

#define FACE_ID_SAVE_NUMBER 7
#endif

#define FACE_COLOR_WHITE  0x00FFFFFF
#define FACE_COLOR_BLACK  0x00000000
#define FACE_COLOR_RED    0x000000FF
#define FACE_COLOR_GREEN  0x0000FF00
#define FACE_COLOR_BLUE   0x00FF0000
#define FACE_COLOR_YELLOW (FACE_COLOR_RED | FACE_COLOR_GREEN)
#define FACE_COLOR_CYAN   (FACE_COLOR_BLUE | FACE_COLOR_GREEN)
#define FACE_COLOR_PURPLE (FACE_COLOR_BLUE | FACE_COLOR_RED)
#endif

// Enable LED FLASH setting
#define CONFIG_LED_ILLUMINATOR_ENABLED 0

// LED FLASH setup
#if CONFIG_LED_ILLUMINATOR_ENABLED

#define LED_LEDC_GPIO            22  //configure LED pin
#define CONFIG_LED_MAX_INTENSITY 255

int led_duty = 0;
bool isStreaming = false;

#endif

typedef struct {
  httpd_req_t *req;
  size_t len;
} jpg_chunking_t;

#define PART_BOUNDARY "123456789000000000000987654321"
static const char *_STREAM_CONTENT_TYPE = "multipart/x-mixed-replace;boundary=" PART_BOUNDARY;
static const char *_STREAM_BOUNDARY = "\r\n--" PART_BOUNDARY "\r\n";
static const char *_STREAM_PART = "Content-Type: image/jpeg\r\nContent-Length: %u\r\nX-Timestamp: %d.%06d\r\n\r\n";

httpd_handle_t stream_httpd = NULL;
httpd_handle_t camera_httpd = NULL;

#if CONFIG_ESP_FACE_DETECT_ENABLED

static int8_t detection_enabled = 0;

// #if TWO_STAGE
// static HumanFaceDetectMSR01 s1(0.1F, 0.5F, 10, 0.2F);
// static HumanFaceDetectMNP01 s2(0.5F, 0.3F, 5);
// #else
// static HumanFaceDetectMSR01 s1(0.3F, 0.5F, 10, 0.2F);
// #endif

#if CONFIG_ESP_FACE_RECOGNITION_ENABLED
static int8_t recognition_enabled = 0;
static int8_t is_enrolling = 0;

#if QUANT_TYPE
// S16 model
FaceRecognition112V1S16 recognizer;
#else
// S8 model
FaceRecognition112V1S8 recognizer;
#endif
#endif

#endif

typedef struct {
  size_t size;   //number of values used for filtering
  size_t index;  //current value index
  size_t count;  //value count
  int sum;
  int *values;  //array to be filled with values
} ra_filter_t;

static ra_filter_t ra_filter;

static ra_filter_t *ra_filter_init(ra_filter_t *filter, size_t sample_size) {
  memset(filter, 0, sizeof(ra_filter_t));

  filter->values = (int *)malloc(sample_size * sizeof(int));
  if (!filter->values) {
    return NULL;
  }
  memset(filter->values, 0, sample_size * sizeof(int));

  filter->size = sample_size;
  return filter;
}

#if ARDUHAL_LOG_LEVEL >= ARDUHAL_LOG_LEVEL_INFO
static int ra_filter_run(ra_filter_t *filter, int value) {
  if (!filter->values) {
    return value;
  }
  filter->sum -= filter->values[filter->index];
  filter->values[filter->index] = value;
  filter->sum += filter->values[filter->index];
  filter->index++;
  filter->index = filter->index % filter->size;
  if (filter->count < filter->size) {
    filter->count++;
  }
  return filter->sum / filter->count;
}
#endif

#if CONFIG_ESP_FACE_DETECT_ENABLED
#if CONFIG_ESP_FACE_RECOGNITION_ENABLED
static void rgb_print(fb_data_t *fb, uint32_t color, const char *str) {
  fb_gfx_print(fb, (fb->width - (strlen(str) * 14)) / 2, 10, color, str);
}

static int rgb_printf(fb_data_t *fb, uint32_t color, const char *format, ...) {
  char loc_buf[64];
  char *temp = loc_buf;
  int len;
  va_list arg;
  va_list copy;
  va_start(arg, format);
  va_copy(copy, arg);
  len = vsnprintf(loc_buf, sizeof(loc_buf), format, arg);
  va_end(copy);
  if (len >= sizeof(loc_buf)) {
    temp = (char *)malloc(len + 1);
    if (temp == NULL) {
      return 0;
    }
  }
  vsnprintf(temp, len + 1, format, arg);
  va_end(arg);
  rgb_print(fb, color, temp);
  if (len > 64) {
    free(temp);
  }
  return len;
}
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
